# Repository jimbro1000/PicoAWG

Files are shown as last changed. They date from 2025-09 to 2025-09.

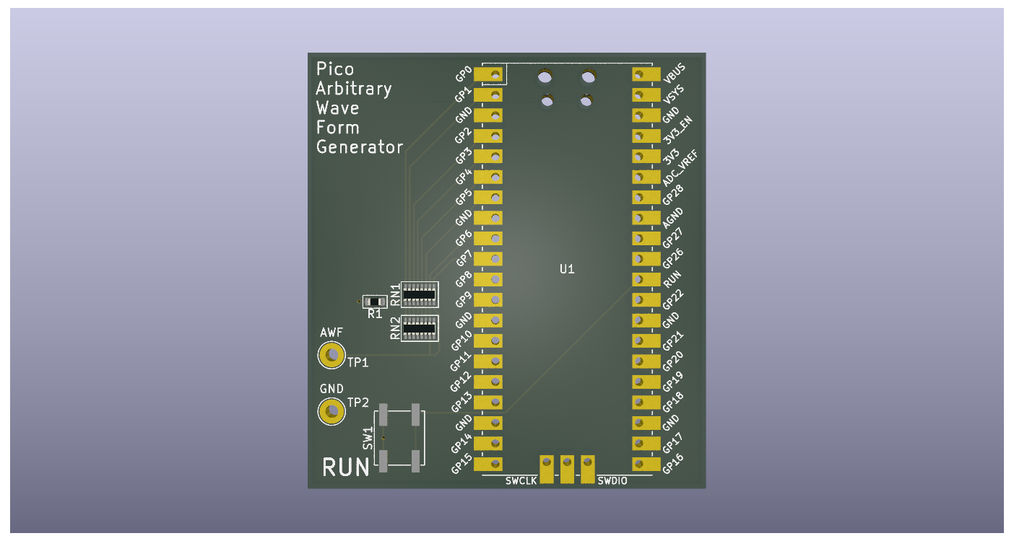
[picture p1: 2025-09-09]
PicoAWG.png

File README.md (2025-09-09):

# Pi Pico AWG

The repository contains the design for a PCB to host
a Raspberry Pi Pico acting as an arbitrary wave
form generator

## Design

This is a prototype design.

The PCB is not optimised for size and the DAC can
be reduced to a single component. Optimisation of
the design could reduce the size of the board
substantially. The Pico device can be swapped out
for a smaller design than the official Pico
provided the exposed GPIO pins meet the requirements
of the AWG code (8 sequentially numbered IO pins).

## Software

The python code included is not my own and has been
taken from an instructables page by rgco 
https://www.instructables.com/Arbitrary-Wave-Generator-With-the-Raspberry-Pi-Pic/

## Usage

The pico must be operating with micropython installed
as a base requisite.

By default the pico requires a computer host to upload
and run the required python code. This is a minimally
interactive process and requires the user to hard code
the desired frequency and wave form.

The python code generates a set of digital samples (from
4096 samples up to 65536 samples). Once generated the pico
will automatically replay the sample on loop.

If the code is renamed as "main.py" and uploaded to the
pico it will automatically run that code on boot allowing
the board to be integrated with another system.

## Issues

The RUN button is currently ineffective, this was
tested on breadboard but does not appear to be
operating. It is also worth noting that contrary
to the software notes it actually behaves as a 
HALT operation intead of RUN.

In order to achieve reasonable accuracy the 
generated wave form requires a high sample size to
avoid jitter. Generating larger sample sizes increases
the time required to begin producing the wave form
output.

The micropython firmware and supplied python code 
currently have a problem working on the Pico 2. This
has been previously tested as working and the cause
of the fault is not yet known.

## License

This design is licensed under the Creative Commons
CC-BY-SA 4.0 International license 
https://creativecommons.org/licenses/by-sa/4.0/deed.en

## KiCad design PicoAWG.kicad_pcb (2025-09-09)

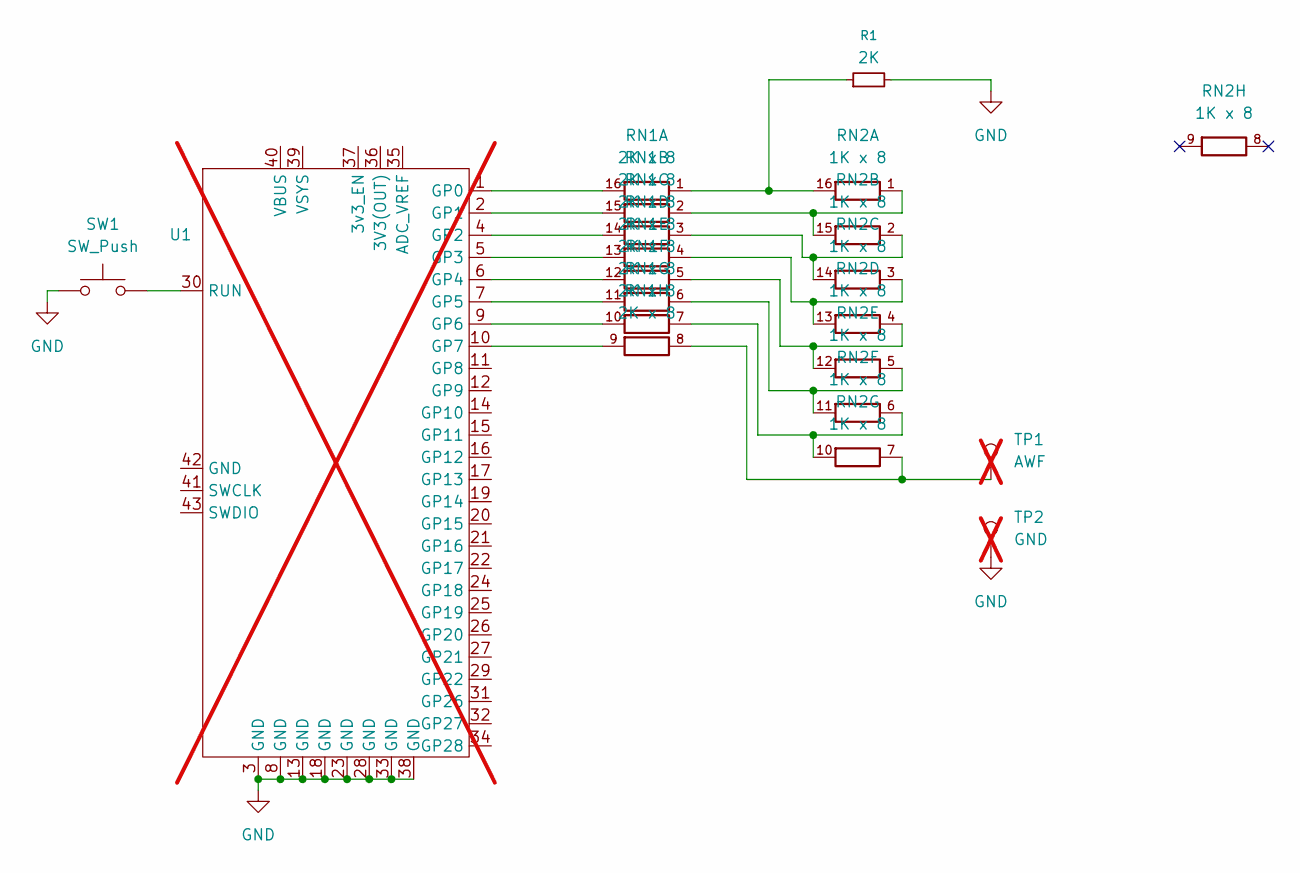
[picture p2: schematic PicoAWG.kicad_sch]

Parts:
R1: 2K; R_0603_1608Metric; LCSC C22975
RN1: 2K x 8; R_Array_Convex_8x0602; LCSC C422185
RN2: 1K x 8; R_Array_Convex_8x0602; LCSC C874604
SW1: SW_Push; SW_SPST_EVQP0; LCSC C3000008
TP1: AWF; TestPoint_Loop_D2.60mm_Drill1.6mm_Beaded; not fitted
TP2: GND; TestPoint_Loop_D2.60mm_Drill1.6mm_Beaded; not fitted
U1: RPi_Pico_SMD_TH; not fitted

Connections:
GND: R1.2, SW1.1, TP2.1, U1.3 (GND), U1.8 (GND), U1.13 (GND), U1.18 (GND), U1.23 (GND), U1.28 (GND), U1.33 (GND), U1.38 (GND)
unnamed: R1.1, RN1.1 (R1.1), RN2.16 (R1.2)
unnamed: RN1.16 (R1.2), U1.1 (GP0)
unnamed: RN1.2 (R2.1), RN2.1 (R1.1), RN2.15 (R2.2)
unnamed: RN1.15 (R2.2), U1.2 (GP1)
unnamed: RN1.3 (R3.1), RN2.2 (R2.1), RN2.14 (R3.2)
unnamed: RN1.14 (R3.2), U1.4 (GP2)
unnamed: RN1.4 (R4.1), RN2.3 (R3.1), RN2.13 (R4.2)
unnamed: RN1.13 (R4.2), U1.5 (GP3)
unnamed: RN1.5 (R5.1), RN2.4 (R4.1), RN2.12 (R5.2)
unnamed: RN1.12 (R5.2), U1.6 (GP4)
unnamed: RN1.6 (R6.1), RN2.5 (R5.1), RN2.11 (R6.2)
unnamed: RN1.11 (R6.2), U1.7 (GP5)
unnamed: RN1.7 (R7.1), RN2.6 (R6.1), RN2.10 (R7.2)
unnamed: RN1.10 (R7.2), U1.9 (GP6)
unnamed: RN1.8 (R8.1), RN2.7 (R7.1), TP1.1
unnamed: RN1.9 (R8.2), U1.10 (GP7)
unnamed: SW1.2, U1.30 (RUN)

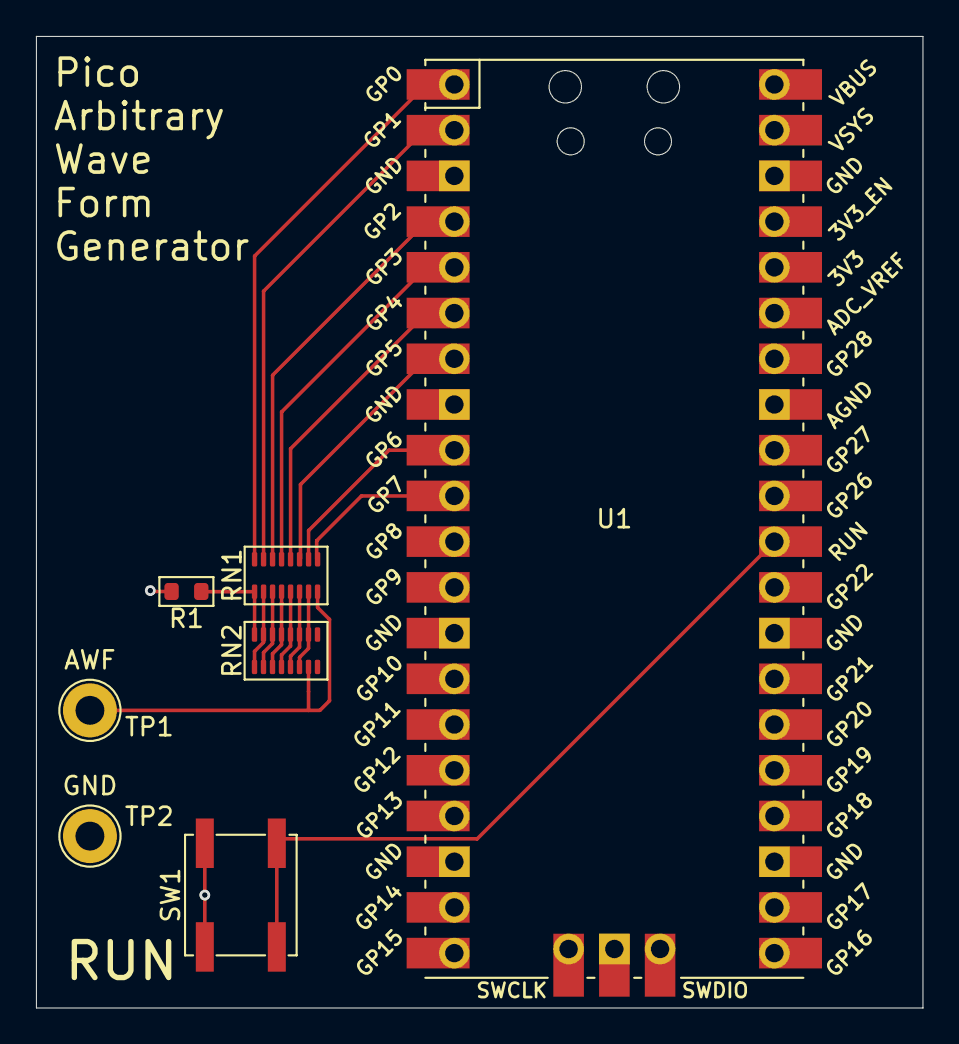
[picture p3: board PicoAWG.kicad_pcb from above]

Board: 2 copper layers, 49.3 x 54.0 mm, 7 parts (0 on the bottom side), 18 nets.

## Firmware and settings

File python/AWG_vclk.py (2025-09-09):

# Arbitrary waveform generator for Rasberry Pi Pico
# Requires 8-bit R2R DAC on pins 0-7. Works for R=1kOhm
# Achieves 125Msps when running 125MHz clock
# Rolf Oldeman, 13/2/2021. CC BY-NC-SA 4.0 licence
# tested with rp2-pico-20210205-unstable-v1.14-8-g1f800cac3.uf2
from machine import Pin,mem32
from rp2 import PIO, StateMachine, asm_pio
from array import array
from utime import sleep
from math import pi,sin,exp,sqrt,floor
from uctypes import addressof
from random import random

fclock=125000000 #clock frequency of the pico

DMA_BASE=0x50000000
CH0_READ_ADDR  =DMA_BASE+0x000
CH0_WRITE_ADDR =DMA_BASE+0x004
CH0_TRANS_COUNT=DMA_BASE+0x008
CH0_CTRL_TRIG  =DMA_BASE+0x00c
CH0_AL1_CTRL   =DMA_BASE+0x010
CH1_READ_ADDR  =DMA_BASE+0x040
CH1_WRITE_ADDR =DMA_BASE+0x044
CH1_TRANS_COUNT=DMA_BASE+0x048
CH1_CTRL_TRIG  =DMA_BASE+0x04c
CH1_AL1_CTRL   =DMA_BASE+0x050

PIO0_BASE      =0x50200000
PIO0_TXF0      =PIO0_BASE+0x10
PIO0_SM0_CLKDIV=PIO0_BASE+0xc8

#state machine that just pushes bytes to the pins
@asm_pio(out_init=(PIO.OUT_HIGH,PIO.OUT_HIGH,PIO.OUT_HIGH,PIO.OUT_HIGH,PIO.OUT_HIGH,PIO.OUT_HIGH,PIO.OUT_HIGH,PIO.OUT_HIGH),
         out_shiftdir=PIO.SHIFT_RIGHT, autopull=True, pull_thresh=32)
def stream():
    out(pins,8)

sm = StateMachine(0, stream, freq=125000000, out_base=Pin(0))
sm.active(1)

#2-channel chained DMA. channel 0 does the transfer, channel 1 reconfigures
p=array('I',[0]) #global 1-element array
def startDMA(ar,nword):
    #first disable the DMAs to prevent corruption while writing
    mem32[CH0_AL1_CTRL]=0
    mem32[CH1_AL1_CTRL]=0
    #setup first DMA which does the actual transfer
    mem32[CH0_READ_ADDR]=addressof(ar)
    mem32[CH0_WRITE_ADDR]=PIO0_TXF0
    mem32[CH0_TRANS_COUNT]=nword
    IRQ_QUIET=0x1 #do not generate an interrupt
    TREQ_SEL=0x00 #wait for PIO0_TX0
    CHAIN_TO=1    #start channel 1 when done
    RING_SEL=0
    RING_SIZE=0   #no wrapping
    INCR_WRITE=0  #for write to array
    INCR_READ=1   #for read from array
    DATA_SIZE=2   #32-bit word transfer
    HIGH_PRIORITY=1
    EN=1
    CTRL0=(IRQ_QUIET<<21)|(TREQ_SEL<<15)|(CHAIN_TO<<11)|(RING_SEL<<10)|(RING_SIZE<<9)|(INCR_WRITE<<5)|(INCR_READ<<4)|(DATA_SIZE<<2)|(HIGH_PRIORITY<<1)|(EN<<0)
    mem32[CH0_AL1_CTRL]=CTRL0
    #setup second DMA which reconfigures the first channel
    p[0]=addressof(ar)
    mem32[CH1_READ_ADDR]=addressof(p)
    mem32[CH1_WRITE_ADDR]=CH0_READ_ADDR
    mem32[CH1_TRANS_COUNT]=1
    IRQ_QUIET=0x1 #do not generate an interrupt
    TREQ_SEL=0x3f #no pacing
    CHAIN_TO=0    #start channel 0 when done
    RING_SEL=0
    RING_SIZE=0   #no wrapping
    INCR_WRITE=0  #single write
    INCR_READ=0   #single read
    DATA_SIZE=2   #32-bit word transfer
    HIGH_PRIORITY=1
    EN=1
    CTRL1=(IRQ_QUIET<<21)|(TREQ_SEL<<15)|(CHAIN_TO<<11)|(RING_SEL<<10)|(RING_SIZE<<9)|(INCR_WRITE<<5)|(INCR_READ<<4)|(DATA_SIZE<<2)|(HIGH_PRIORITY<<1)|(EN<<0)
    mem32[CH1_CTRL_TRIG]=CTRL1



def setupwave(buf,f,w):
    div=fclock/(f*maxnsamp) # required clock division for maximum buffer size
    if div<1.0:  #can't speed up clock, duplicate wave instead
        dup=int(1.0/div)
        nsamp=int((maxnsamp*div*dup+0.5)/4)*4 #force multiple of 4
        clkdiv=1
    else:        #stick with integer clock division only
        clkdiv=int(div)+1
        nsamp=int((maxnsamp*div/clkdiv+0.5)/4)*4 #force multiple of 4
        dup=1

    #fill the buffer
    for isamp in range(nsamp):
        buf[isamp]=max(0,min(255,int(256*eval(w,dup*(isamp+0.5)/nsamp))))

    #set the clock divider
    clkdiv_int=min(clkdiv,65535) 
    clkdiv_frac=0 #fractional clock division results in jitter
    mem32[PIO0_SM0_CLKDIV]=(clkdiv_int<<16)|(clkdiv_frac<<8)

    #start DMA
    startDMA(buf,int(nsamp/4))


#evaluate the content of a wave
def eval(w,x):
    m,s,p=1.0,0.0,0.0
    if 'phasemod' in w.__dict__:
        p=eval(w.phasemod,x)
    if 'mult' in w.__dict__:
        m=eval(w.mult,x)
    if 'sum' in w.__dict__:
        s=eval(w.sum,x)
    x=x*w.replicate-w.phase-p
    x=x-floor(x)  #reduce x to 0.0-1.0 range
    v=w.func(x,w.pars)
    v=v*w.amplitude*m
    v=v+w.offset+s
    return v

#some common waveforms. combine with sum,mult,phasemod
def sine(x,pars):
    return sin(x*2*pi)
def pulse(x,pars): #risetime,uptime,falltime
    if x<pars[0]: return x/pars[0]
    if x<pars[0]+pars[1]: return 1.0
    if x<pars[0]+pars[1]+pars[2]: return 1.0-(x-pars[0]-pars[1])/pars[2]
    return 0.0
def gaussian(x,pars):
    return exp(-((x-0.5)/pars[0])**2)
def sinc(x,pars):
    if x==0.5: return 1.0
    else: return sin((x-0.5)/pars[0])/((x-0.5)/pars[0])
def exponential(x,pars):
    return exp(-x/pars[0])
def noise(x,pars): #p0=quality: 1=uniform >10=gaussian
    return sum([random()-0.5 for _ in range(pars[0])])*sqrt(12/pars[0])
    

#make buffers for the waveform.
#large buffers give better results but are slower to fill
maxnsamp=4096 #must be a multiple of 4. miximum size is 65536
wavbuf={}
wavbuf[0]=bytearray(maxnsamp)
wavbuf[1]=bytearray(maxnsamp)
ibuf=0

#empty class just to attach properties to
class wave:
    pass

wave1=wave()
wave1.amplitude=1.0
wave1.offset=0.0
wave1.phase=0.0
wave1.replicate=1
wave1.func=pulse
#parameters: [rise, duty, fall] 
wave1.pars=[0.0,0.6,0.0]

#step through frequencies
freq=3579540
setupwave(wavbuf[0],freq,wave1)
